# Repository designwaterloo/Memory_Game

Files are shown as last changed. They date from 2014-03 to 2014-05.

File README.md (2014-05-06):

Memory Game
===========

Simple application for teaching basic circuit design and microcontroller capabilities. Includes setup mode operation, and a memory game with coloured LEDs and audio output. 

Gameplay
---------

* When the device is powered up (by connecting the battery), all four LEDs will blink in sequence and a two note melody will play.
* To enter gameplay mode, press the ‘S2’ switch on the microcontroller board.
* When the device enters gameplay mode, all four LEDs will blink in sequence and a six note melody will play.
* This will be immediately followed by a single blink of an LED, and a corresponding single note will be played.
* The object of the game is to copy the sequence using the corresponding buttons.
* If the sequence is copied correctly, the sequence will replay with the addition of a new LED flash and note.
* If you copy the sequence incorrectly, a low tone will play and the game will restart.
* You can replay your highscore at anytime by pressing the ‘S2’ switch while in gameplay mode.
* You can reset the entire device by pressing the ‘RESET’ switch or temporarily disconnecting the power source.

Folder Contents
---------------

**Memory_Game/Memory_Game** - Source code for this project.  Written for [Energia] (http://energia.nu/).

**Memory_Game/Fritzing** - Schemtic files creted using [Fritzing] (http://fritzing.org/).

**Memory_Game/Documentation** - Detailed assembly instructions, gameplay information, presentation material, and BOM.

**Presentation Material** - http://prezi.com/puz2dcljfam3/?utm_campaign=share&utm_medium=copy&rc=ex0share

Licenses
========

Documentation
-------------
This work is licensed under the Creative Commons Attribution 4.0 International License. To view a copy of this license, visit http://creativecommons.org/licenses/by/4.0/.

Software
--------

Software License Agreement (BSD License)
Copyright (c) 2014, Ryan Walker
All rights reserved.

Redistribution and use in source and binary forms, with or without
modification, are permitted provided that the following conditions are met:

1. Redistributions of source code must retain the above copyright notice, this
   list of conditions and the following disclaimer. 
2. Redistributions in binary form must reproduce the above copyright notice,
   this list of conditions and the following disclaimer in the documentation
   and/or other materials provided with the distribution.

THIS SOFTWARE IS PROVIDED BY THE COPYRIGHT HOLDERS AND CONTRIBUTORS "AS IS" AND
ANY EXPRESS OR IMPLIED WARRANTIES, INCLUDING, BUT NOT LIMITED TO, THE IMPLIED
WARRANTIES OF MERCHANTABILITY AND FITNESS FOR A PARTICULAR PURPOSE ARE
DISCLAIMED. IN NO EVENT SHALL THE COPYRIGHT OWNER OR CONTRIBUTORS BE LIABLE FOR
ANY DIRECT, INDIRECT, INCIDENTAL, SPECIAL, EXEMPLARY, OR CONSEQUENTIAL DAMAGES
(INCLUDING, BUT NOT LIMITED TO, PROCUREMENT OF SUBSTITUTE GOODS OR SERVICES;
LOSS OF USE, DATA, OR PROFITS; OR BUSINESS INTERRUPTION) HOWEVER CAUSED AND
ON ANY THEORY OF LIABILITY, WHETHER IN CONTRACT, STRICT LIABILITY, OR TORT
(INCLUDING NEGLIGENCE OR OTHERWISE) ARISING IN ANY WAY OUT OF THE USE OF THIS
SOFTWARE, EVEN IF ADVISED OF THE POSSIBILITY OF SUCH DAMAGE.

The views and conclusions contained in the software and documentation are those
of the authors and should not be interpreted as representing official policies, 
either expressed or implied, of the FreeBSD Project.

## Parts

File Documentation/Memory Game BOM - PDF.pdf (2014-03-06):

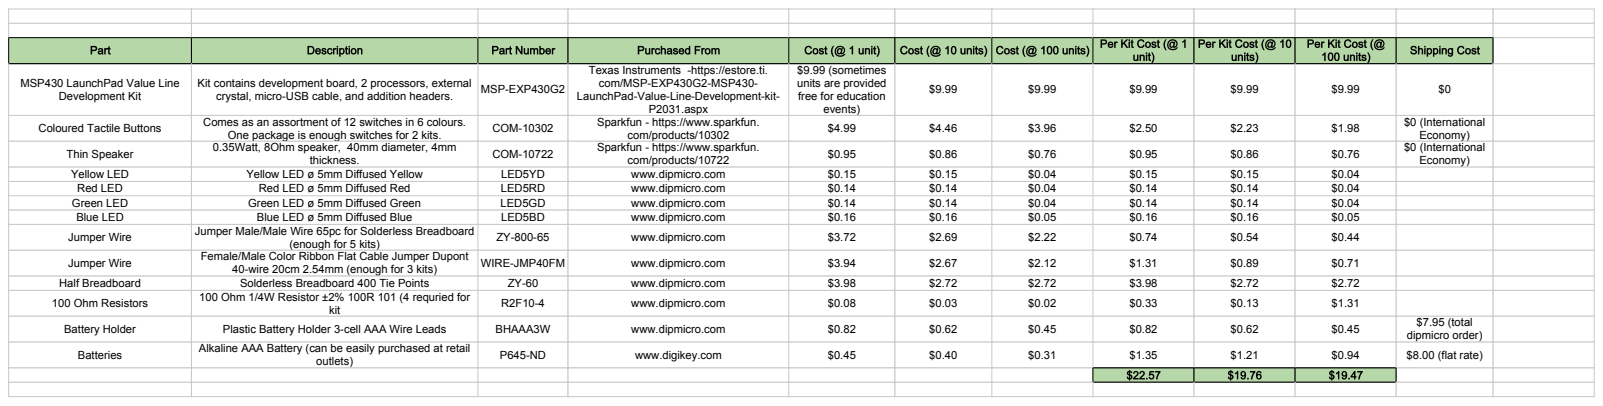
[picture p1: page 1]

Part | Description | Part Number | Purchased From | Cost (@ 1 unit) | Cost (@ 10 units) | Cost (@ 100 units) | Per Kit Cost (@ 1 unit) | Per Kit Cost (@ 10 units) | Per Kit Cost (@ 100 units) | Shipping Cost

MSP430 LaunchPad Value Line Development Kit | Kit contains development board, 2 processors, external crystal, micro-USB cable, and addition headers. | MSP-EXP430G2 | Texas Instruments -https://estore.ti.com/MSP-EXP430G2-MSP430-LaunchPad-Value-Line-Development-kit-P2031.aspx | $9.99 (sometimes units are provided free for education events) | $9.99 | $9.99 | $9.99 | $9.99 | $9.99 | $0

Coloured Tactile Buttons | Comes as an assortment of 12 switches in 6 colours. One package is enough switches for 2 kits. | COM-10302 | Sparkfun - https://www.sparkfun.com/products/10302 | $4.99 | $4.46 | $3.96 | $2.50 | $2.23 | $1.98 | $0 (International Economy)

Thin Speaker | 0.35Watt, 8Ohm speaker, 40mm diameter, 4mm thickness. | COM-10722 | Sparkfun - https://www.sparkfun.com/products/10722 | $0.95 | $0.86 | $0.76 | $0.95 | $0.86 | $0.76 | $0 (International Economy)

Yellow LED | Yellow LED ø 5mm Diffused Yellow | LED5YD | www.dipmicro.com | $0.15 | $0.15 | $0.04 | $0.15 | $0.15 | $0.04
Red LED | Red LED ø 5mm Diffused Red | LED5RD | www.dipmicro.com | $0.14 | $0.14 | $0.04 | $0.14 | $0.14 | $0.04
Green LED | Green LED ø 5mm Diffused Green | LED5GD | www.dipmicro.com | $0.14 | $0.14 | $0.04 | $0.14 | $0.14 | $0.04
Blue LED | Blue LED ø 5mm Diffused Blue | LED5BD | www.dipmicro.com | $0.16 | $0.16 | $0.05 | $0.16 | $0.16 | $0.05
Jumper Wire | Jumper Male/Male Wire 65pc for Solderless Breadboard (enough for 5 kits) | ZY-800-65 | www.dipmicro.com | $3.72 | $2.69 | $2.22 | $0.74 | $0.54 | $0.44

Jumper Wire | Female/Male Color Ribbon Flat Cable Jumper Dupont 40-wire 20cm 2.54mm (enough for 3 kits) | WIRE-JMP40FM | www.dipmicro.com | $3.94 | $2.67 | $2.12 | $1.31 | $0.89 | $0.71

Half Breadboard | Solderless Breadboard 400 Tie Points | ZY-60 | www.dipmicro.com | $3.98 | $2.72 | $2.72 | $3.98 | $2.72 | $2.72
100 Ohm Resistors | 100 Ohm 1/4W Resistor ±2% 100R 101 (4 requried for kit | R2F10-4 | www.dipmicro.com | $0.08 | $0.03 | $0.02 | $0.33 | $0.13 | $1.31

Battery Holder | Plastic Battery Holder 3-cell AAA Wire Leads | BHAAA3W | www.dipmicro.com | $0.82 | $0.62 | $0.45 | $0.82 | $0.62 | $0.45 | $7.95 (total dipmicro order)

Batteries | Alkaline AAA Battery (can be easily purchased at retail outlets) | P645-ND | www.digikey.com | $0.45 | $0.40 | $0.31 | $1.35 | $1.21 | $0.94 | $8.00 (flat rate)

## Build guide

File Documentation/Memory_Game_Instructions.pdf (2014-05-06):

# Memory Game - Assembly Instructions 25 30

# Step 1:

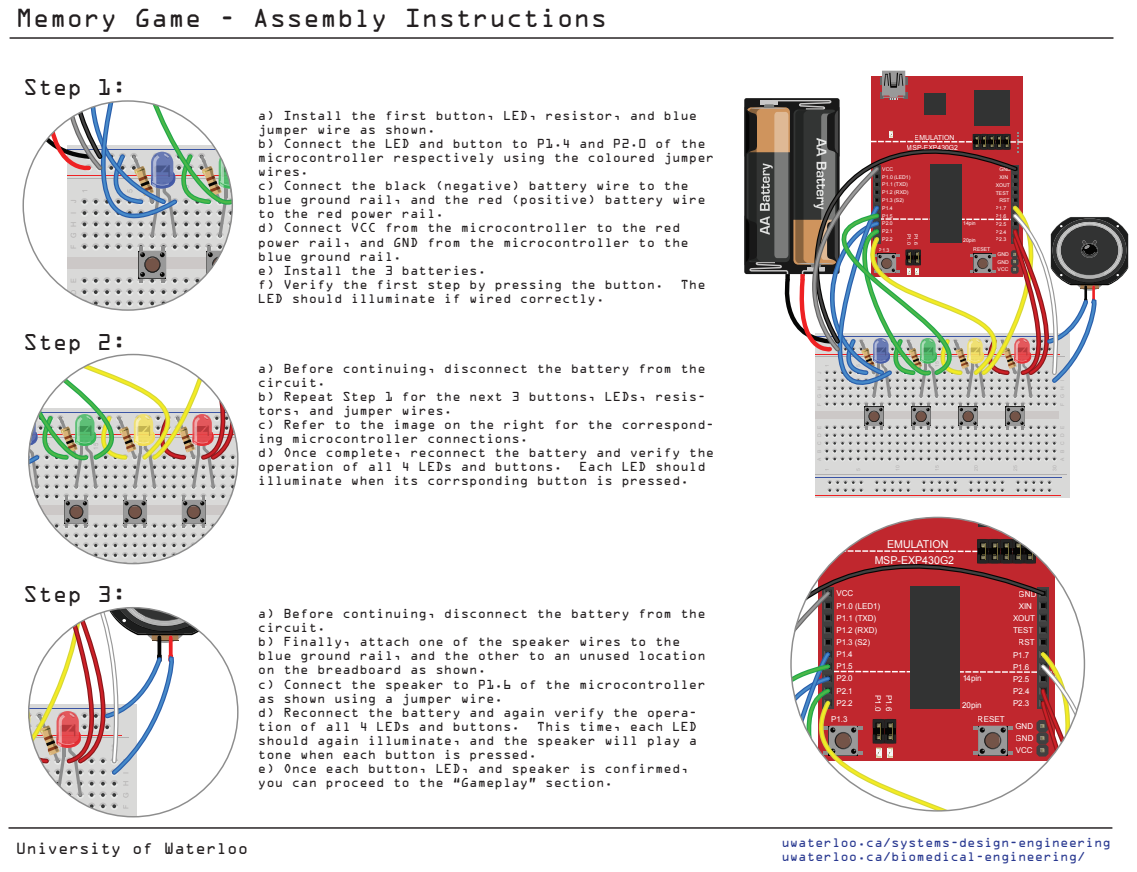
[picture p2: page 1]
RESET; 14pin; 20pin; GND; EMULATION; GND VCC; GND XIN; RST P1.7; TEST; XOUT; VCC P1.0 (LED1); P1.2 (RXD); P1.1 (TXD); MSP-EXP430G2; VCC; Step 2:; Step 3:; f) Verify the first step by pressing the button.; The; operation of all 4 LEDs and buttons.; Each LED should; tion of all 4 LEDs and buttons.; This time, each LED

a) Install the first button, LED, resistor, and blue
jumper wire as shown.
b) Connect the LED and button to P1.4 and P2.0 of the
microcontroller respectively using the coloured jumper
wires.
c) Connect the black (negative) battery wire to the
blue ground rail, and the red (positive) battery wire
to the red power rail.
d) Connect VCC from the microcontroller to the red
power rail, and GND from the microcontroller to the
blue ground rail.
e) Install the 3 batteries.
LED should illuminate if wired correctly.

a) Before continuing, disconnect the battery from the
circuit.
b) Repeat Step 1 for the next 3 buttons, LEDs, resis-
tors, and jumper wires.
c) Refer to the image on the right for the correspond-
ing microcontroller connections.
d) Once complete, reconnect the battery and verify the
illuminate when its corrsponding button is pressed.

b) Finally, attach one of the speaker wires to the
blue ground rail, and the other to an unused location
on the breadboard as shown.
c) Connect the speaker to P1.6 of the microcontroller
as shown using a jumper wire.
d) Reconnect the battery and again verify the opera-
should again illuminate, and the speaker will play a
tone when each button is pressed.
e) Once each button, LED, and speaker is confirmed,
you can proceed to the “Gameplay” section.

uwaterloo.ca/systems-design-engineering
uwaterloo.ca/biomedical-engineering/

University of Waterloo

# Memory Game - Gameplay & Schematic

# Gameplay:

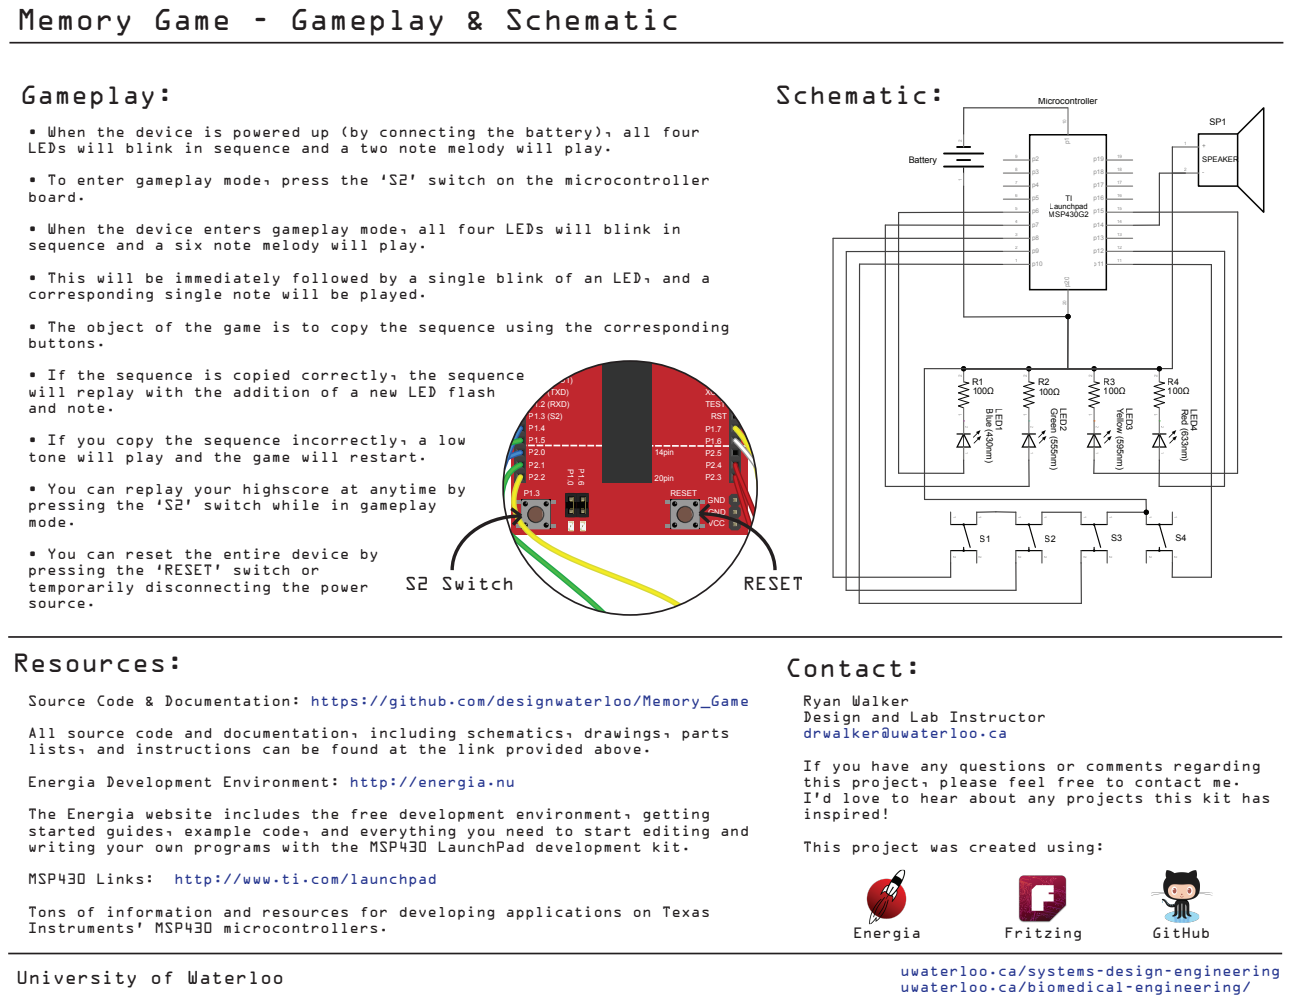
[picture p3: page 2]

• When the device is powered up (by connecting the battery), all four
LEDs will blink in sequence and a two note melody will play.

• To enter gameplay mode, press the ‘S2’ switch on the microcontroller
board.

• When the device enters gameplay mode, all four LEDs will blink in
sequence and a six note melody will play.

• This will be immediately followed by a single blink of an LED, and a
corresponding single note will be played.

• The object of the game is to copy the sequence using the corresponding
buttons.

• If the sequence is copied correctly, the sequence
will replay with the addition of a new LED flash
and note.

• If you copy the sequence incorrectly, a low
tone will play and the game will restart.

• You can replay your highscore at anytime by
pressing the ‘S2’ switch while in gameplay
mode.

• You can reset the entire device by
pressing the ‘RESET’ switch or
temporarily disconnecting the power
source.

Source Code & Documentation: https://github.com/designwaterloo/Memory_Game

Ryan Walker
Design and Lab Instructor
drwalker@uwaterloo.ca

All source code and documentation, including schematics, drawings, parts
lists, and instructions can be found at the link provided above.

If you have any questions or comments regarding
this project, please feel free to contact me.
I’d love to hear about any projects this kit has
inspired!

Energia Development Environment: http://energia.nu

The Energia website includes the free development environment, getting
started guides, example code, and everything you need to start editing and
writing your own programs with the MSP430 LaunchPad development kit.

This project was created using:

Tons of information and resources for developing applications on Texas
Instruments’ MSP430 microcontrollers.

uwaterloo.ca/systems-design-engineering
uwaterloo.ca/biomedical-engineering/

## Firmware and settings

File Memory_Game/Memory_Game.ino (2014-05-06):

/**************************************************************************/
/* 
   @file     Memory_Game.ino
   @author   Ryan Walker (University of Waterloo)
   @license  BSD (see README.md)
   
   Simple application for teaching basic circuit design and microcontroller 
   capabilities. Includes setup mode operation, and a memory game with 
   coloured LEDs and audio output.
*/
/**************************************************************************/

// Defining the pin mapping for the various functions
#define BUTTON_1       P2_0
#define BUTTON_2       P2_1
#define BUTTON_3       P2_2
#define BUTTON_4       P2_3
#define SWITCH         P1_3
#define LED_1          P1_4
#define LED_2          P1_5
#define LED_3          P1_7
#define LED_4          P2_4
#define SPEAKER        P1_6
#define RANDOM_SEED    A1


// Global Variables
uint8_t sequence[50], player_input[50], highscore[50];
uint8_t game_level, highscore_level;
uint16_t game_speed, input_speed;

// Setup and initialize microcontroller functionality (this function runs once at startup)
void setup() {
   
  // Allows serial communication to terminal over USB (not used for this project)
  Serial.begin(9600);

  // Setup the 4 game LEDs as outputs
  pinMode(LED_1, OUTPUT);
  pinMode(LED_2, OUTPUT);
  pinMode(LED_3, OUTPUT);
  pinMode(LED_4, OUTPUT);  
  
  // Setup the speaker as an output
  pinMode(SPEAKER, OUTPUT);
 
  // Setup the 4 games buttons, and program switch as inputs
  pinMode(BUTTON_1, INPUT_PULLUP);
  pinMode(BUTTON_2, INPUT_PULLUP);
  pinMode(BUTTON_3, INPUT_PULLUP);
  pinMode(BUTTON_4, INPUT_PULLUP);
  pinMode(SWITCH, INPUT_PULLUP);
   
  // Setup Pin 1.1 as an analog input for randon number generator seed
  pinMode(RANDOM_SEED, INPUT);
 
  // Generate the Random Sequence
  randomSeed(analogRead(RANDOM_SEED));
  for (int i=0; i<=50; i++){
    sequence[i] = random(1, 5);
  }
 
  //Initialize LEDs in the OFF state
  digitalWrite(LED_1, LOW);
  digitalWrite(LED_2, LOW);
  digitalWrite(LED_3, LOW);
  digitalWrite(LED_4, LOW);
 
  // Initial Game State
  highscore_level = 0;    // Reset the highscore keeper to zero
  game_level = 0;         // Reset the current game level to zero
  game_speed = 500;       // Set the speed of the game sequence to 500 milliseconds
  input_speed = 500;      // Set the input speed to 500 milliseconds
  
  // Run a brief LED and sound sequence to indicate the program has started
  program_init_sequence();  
  
  // -------------------------- Assembly Verification --------------------------- //
  //
  // This section of code is used to check functionality of the circuit during the
  // assembly procedure.  It is intended solely as a teaching tool and has no effect
  // on game play.  The 'Assembly Verification' secion can be deleted if only game
  // play is desired and this game will still function correctly.
  
  // When a button is pressed, turn on corresponding LED and play a tone
  while(1)
  {  
    // When S2 is pressed, exit 'Assembly Verification' mode and start gameplay
    if (digitalRead(SWITCH) == LOW)
    {
      break;
    }
    else if (digitalRead(BUTTON_1) == LOW)
    {      
      play(1, input_speed);  
    }
    else if (digitalRead(BUTTON_2) == LOW)
    {
      play(2,input_speed); 
    }
    else if (digitalRead(BUTTON_3) == LOW)
    {
      play(3,input_speed);
    }
    else if (digitalRead(BUTTON_4) == LOW)
    {
      play(4,input_speed);
    }
      
  }
  
  // ------------------------ Assembly Verification End-------------------------- //
  
   // Play the Game Intro Sequence of lights and sound
   game_start_sequence();  
}


// The main loop for the program.  This section of code repeats as long as the device
// is powered up.
void loop()
{  
  
  // --------------------------------- Gameplay --------------------------------- //
  
  // Play the game sequence
  for (int j=0; j<=game_level; j++)
  {
    play(sequence[j], game_speed);
  }

  // Get input sequence from the user
  for (int i=0; i<=game_level; i++)
  {
    while(1)
    {
      if (digitalRead(BUTTON_1) == LOW)
      {
        player_input[i] = 1;
        play(1, input_speed);  
        break;
      }
     else if (digitalRead(BUTTON_2) == LOW)
     {
        player_input[i] = 2;
        play(2,input_speed); 
        break;
      }
      else if (digitalRead(BUTTON_3) == LOW)
      {
        player_input[i] = 3;
        play(3,input_speed);
        break;
      }
      else if (digitalRead(BUTTON_4) == LOW)
      {
        player_input[i] = 4;
        play(4,input_speed);
        break;
      }
    
      if (digitalRead(SWITCH) == LOW)
      {
        high_score_playback(200);
      }
    }
  
    // Check if the input matches the sequence
    if (player_input[i] != sequence[i])            // If incorrect
    {
      if (game_level > highscore_level)            // Check for highscore
      {
        highscore_level = game_level;
        for (int h=0; h<highscore_level; h++)    
        {
          highscore[h] = sequence[h];              // Save highscore
         }
       }
      you_lose();                                  // Play losing tone
      game_level = -1;                             // Reset game level
      delay(1000);
      break;
    }
 
  }

  // Increment game level
  game_level++;                        
  delay(500);
  
}

// A sequence of LED flashes and tones to indicate the program has started
void program_init_sequence()
{
  for (int i=0; i<1; i++){
    digitalWrite(LED_4, LOW);
    digitalWrite(LED_1, HIGH);
    delay(100);
    digitalWrite(LED_2, LOW);
    digitalWrite(LED_1, HIGH);
    delay(100);
    digitalWrite(LED_1, LOW);
    digitalWrite(LED_2, HIGH);
    delay(100);
    digitalWrite(LED_2, LOW);
    digitalWrite(LED_3, HIGH);
    delay(100);
    digitalWrite(LED_3, LOW);
    digitalWrite(LED_4, HIGH);
    delay(100);
  } 
  digitalWrite(LED_4, LOW);
  tone(SPEAKER, 1976);
  delay(60);
  noTone(SPEAKER);
  delay(1);
  tone(SPEAKER, 2637);
  delay(360);
  noTone(SPEAKER);
  delay(1000); 
}


// A sequence of LED flashes and tones to indicate gameplay mode as started
void game_start_sequence()
{
  for (int i=0; i<1; i++){
    digitalWrite(LED_4, LOW);
    digitalWrite(LED_1, HIGH);
    delay(100);
    digitalWrite(LED_2, LOW);
    digitalWrite(LED_1, HIGH);
    delay(100);
    digitalWrite(LED_1, LOW);
    digitalWrite(LED_2, HIGH);
    delay(100);
    digitalWrite(LED_2, LOW);
    digitalWrite(LED_3, HIGH);
    delay(100);
    digitalWrite(LED_3, LOW);
    digitalWrite(LED_4, HIGH);
    delay(100);
  } 
  digitalWrite(LED_4, LOW);
  tone(SPEAKER, 1319);
  delay(120);
  noTone(SPEAKER);
  delay(10);
  
  tone(SPEAKER, 1568);
  delay(120);
  noTone(SPEAKER);
  delay(10);
  
  tone(SPEAKER, 2637);
  delay(120);
  noTone(SPEAKER);
  delay(10);
  
  tone(SPEAKER, 2093);
  delay(120);
  noTone(SPEAKER);
  delay(10);
  
  tone(SPEAKER, 2349);
  delay(120);
  noTone(SPEAKER);
  delay(10);
  
  tone(SPEAKER, 3136);
  delay(120);
  noTone(SPEAKER);
  delay(1000); 
}


// Function used to control LEDs and play tones for each button press
void play(uint8_t button, unsigned int duration)
{
  switch (button) {
    case 1:
      digitalWrite(LED_1, HIGH);
      tone(SPEAKER, 415);
      delay(duration);
      digitalWrite(LED_1, LOW);
      noTone(SPEAKER);
      break;
    case 2:
      digitalWrite(LED_2, HIGH);
      tone(SPEAKER, 310);
      delay(duration);
      digitalWrite(LED_2, LOW);
      noTone(SPEAKER);
      break;
    case 3:
      digitalWrite(LED_3, HIGH);
      tone(SPEAKER, 252);
      delay(duration);
      digitalWrite(LED_3, LOW);
      noTone(SPEAKER);
      break;
    case 4:
      digitalWrite(LED_4, HIGH);
      tone(SPEAKER, 209);
      delay(duration);
      digitalWrite(LED_4, LOW);
      noTone(SPEAKER);
      break;
    default:
      noTone(SPEAKER);
  }
}
  
  
// Function for handling losing  
void you_lose()
{
  // Play losing tone
  tone(SPEAKER, 42);          
  delay(1000);
  noTone(SPEAKER);
  
  // Generate new Random Sequence for next game
  for (int a=0; a<=50; a++){
    sequence[a] = random(1, 5);
  }
}


// Function that plays back the current highscore at a faster rate
void high_score_playback(unsigned int playback_speed)
{
 for (int h=0; h<highscore_level; h++)
 {
  play(highscore[h], playback_speed);
 }
}

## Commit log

2014-02-28 Fritzing Schematic Files
    Fritzing Schematic Files.
    [Memory_Game.fzz]
2014-02-28 Added presentation and instructional material.
    Two pdf documents containing presentation data, assembly instructions,
    and gameplay information.
2014-03-06 Added BOM for kits.
    Uploaded a pdf and spreadsheet detailing kit contents, purchase
    locations, and cost.
    [Memory Game BOM - Spreadsheet.xlsx]
